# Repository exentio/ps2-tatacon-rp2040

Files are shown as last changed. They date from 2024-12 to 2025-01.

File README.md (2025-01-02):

# PS2 Tatacon RP2040 converter
---

Replacement PCB for the PS2 Tatacon (NPC-107) using the Waveshare RP2040-Zero.  
The recommended firmware is GP2040-CE, which provides sub-ms input lag and
allows to use it with both PC and many consoles. The used pins are as follows:  

| Controller Input | RP2040 Pin |
|---|---|
| Right Don | 7 |
| Left Don | 8 |
| Right Ka | 27 |
| Left Ka | 26 |
| Start (yellow wire) | 14 |
| Select (red wire) | 15 |

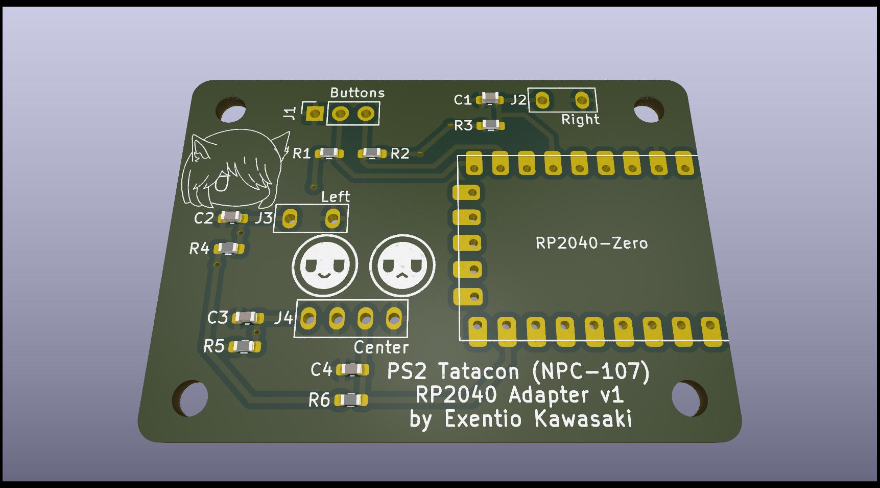
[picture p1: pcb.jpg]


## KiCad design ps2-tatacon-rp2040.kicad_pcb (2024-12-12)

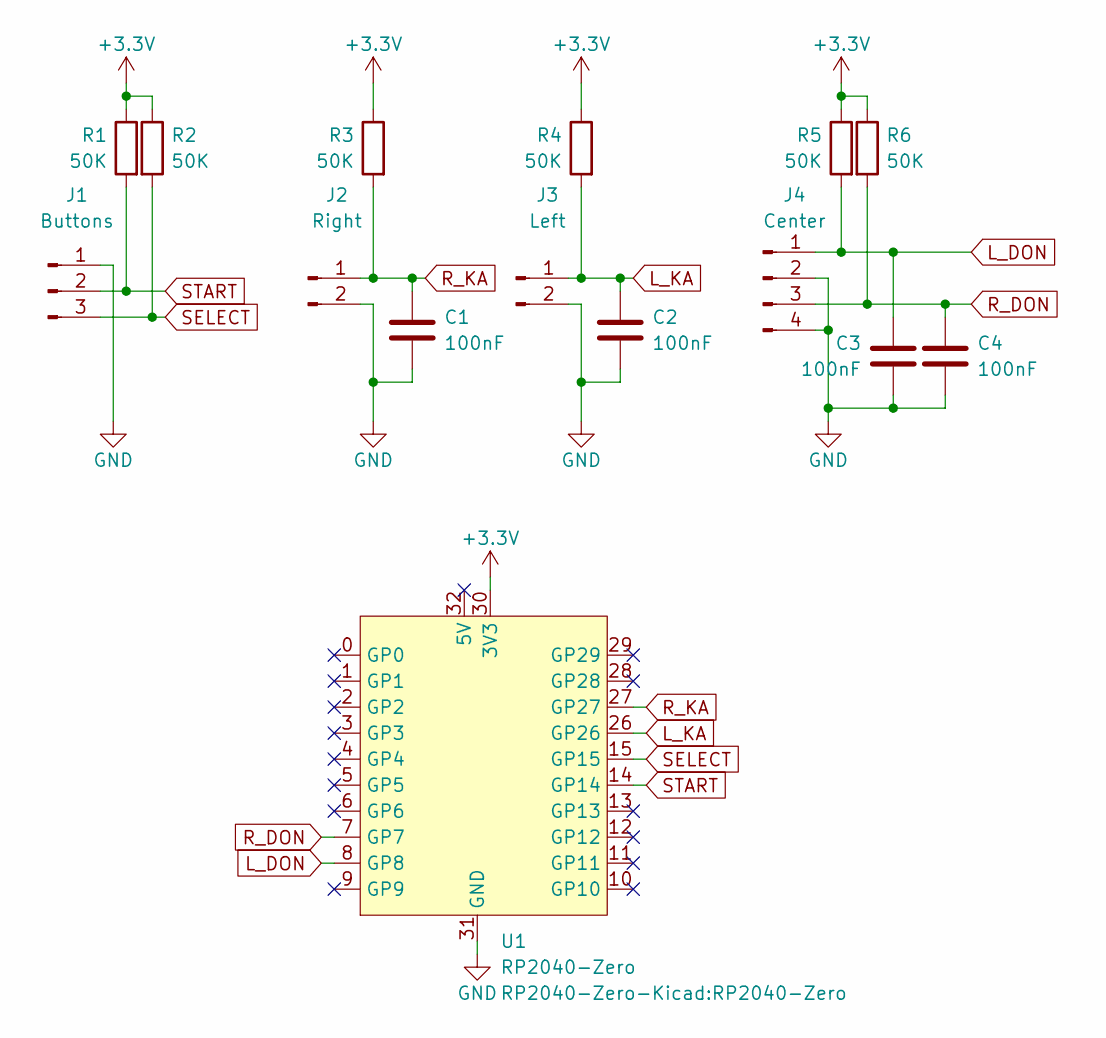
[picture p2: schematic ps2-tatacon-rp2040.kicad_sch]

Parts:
C1, C2, C3, C4: 100nF; C_0603_1608Metric_Pad1.08x0.95mm_HandSolder
J1: Buttons; PinSocket_1x03_P2.54mm_Vertical
J2: Right; PinSocket_1x02_Spaced_P2.00mm
J3: Left; PinSocket_1x02_Spaced_P2.00mm
J4: Center; PinSocket_1x04_P2.5mm_Vertical
R1, R2, R3, R4, R5, R6: 50K; R_0603_1608Metric_Pad0.98x0.95mm_HandSolder
U1: RP2040-Zero

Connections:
+3.3V: R1.1, R2.1, R3.1, R4.1, R5.1, R6.1, U1.30 (3V3)
GND: C1.2, C2.2, C3.2, C4.2, J1.1, J2.2, J3.2, J4.2, J4.4, U1.31 (GND)
L_DON: C3.1, J4.1, R5.2, U1.8 (GP8)
L_KA: C2.1, J3.1, R4.2, U1.26 (GP26)
R_DON: C4.1, J4.3, R6.2, U1.7 (GP7)
R_KA: C1.1, J2.1, R3.2, U1.27 (GP27)
SELECT: J1.3, R2.2, U1.15 (GP15)
START: J1.2, R1.2, U1.14 (GP14)

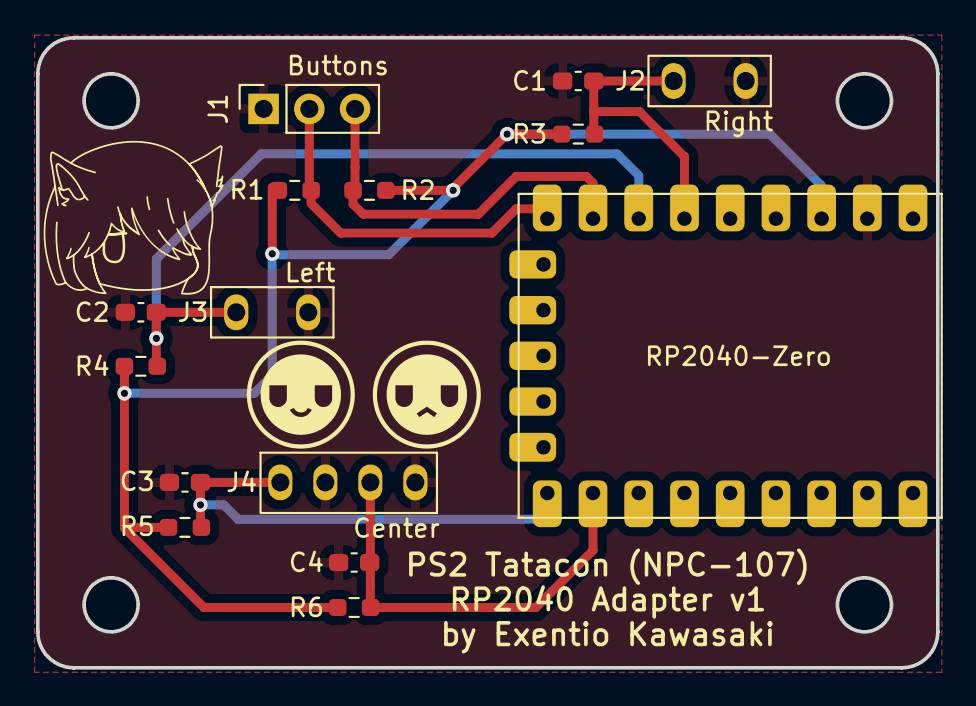
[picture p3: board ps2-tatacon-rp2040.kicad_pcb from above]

Board: 2 copper layers, 50.0 x 35.0 mm, 15 parts (0 on the bottom side), 8 nets.

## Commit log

2024-12-11 Inital board layout
    [ps2-tatacon-rp2040.kicad_pcb, ps2-tatacon-rp2040.kicad_sch]
2024-12-11 Board layout finished, need to fix footprint
    [ps2-tatacon-rp2040.kicad_pcb, ps2-tatacon-rp2040.kicad_sch]
2024-12-12 First revision finished
    [ps2-tatacon-rp2040-B_Cu.gbl, ps2-tatacon-rp2040-B_Mask.gbs, ps2-tatacon-rp2040-B_Paste.gbp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]
2024-12-17 Readme update (start/select wire colors)
